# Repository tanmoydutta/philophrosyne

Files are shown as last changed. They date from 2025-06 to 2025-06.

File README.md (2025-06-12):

# Philophrosyne
A general purpose Bluetooth and WiFi enabled sensor board that has flexible interfaces for I2C, SPI Display and a SEN-54 seneor module.
The unit can be powered by USB-C connector or a LiPo battery. This module has built in battery charging circuit.
The model board - 
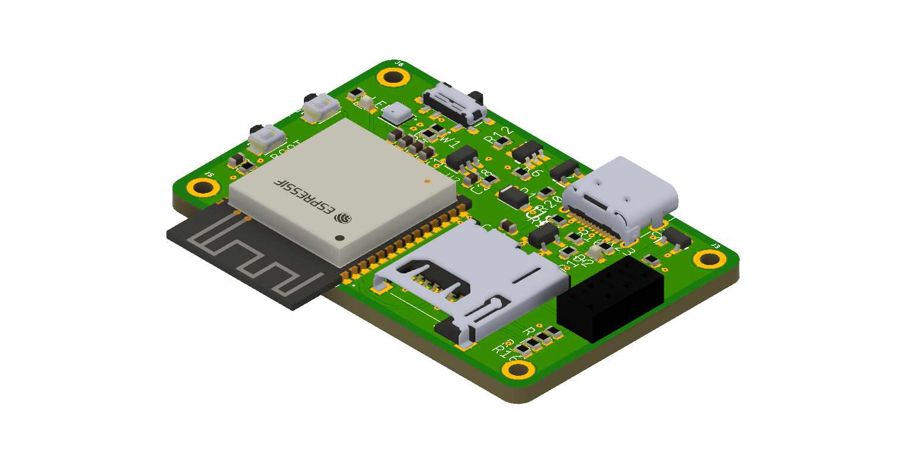
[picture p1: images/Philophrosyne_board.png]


Primary purpose of this board is to interface with SEN-54 sensors. A housing compatible with containing the sensor unit as well as the board is designed.

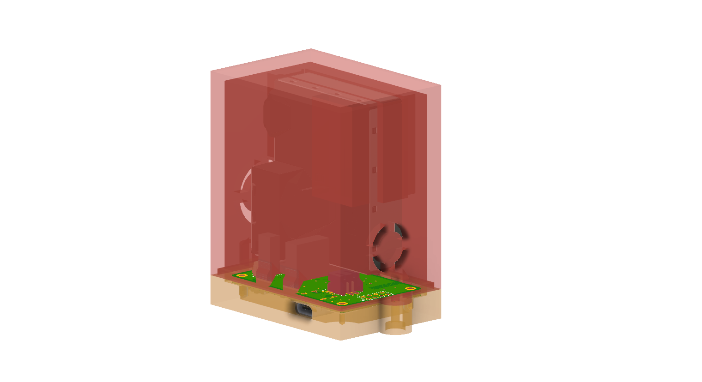
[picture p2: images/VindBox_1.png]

The concept module with coer removed-
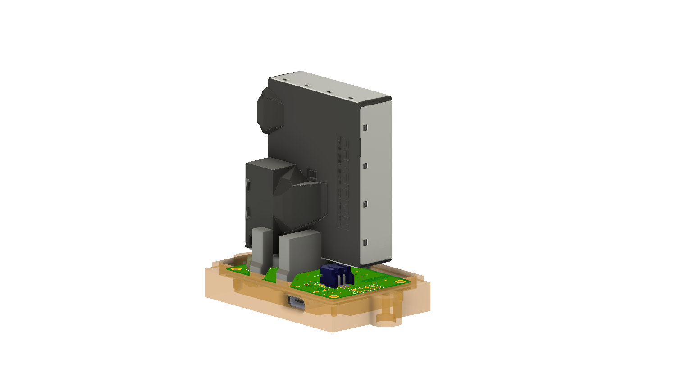
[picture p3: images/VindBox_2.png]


Below is the built module with the sensor and housing -


This is an OSHWA certified hardware - 
<p align="center">
  <a href="https://certification.oshwa.org/nl000030.html">
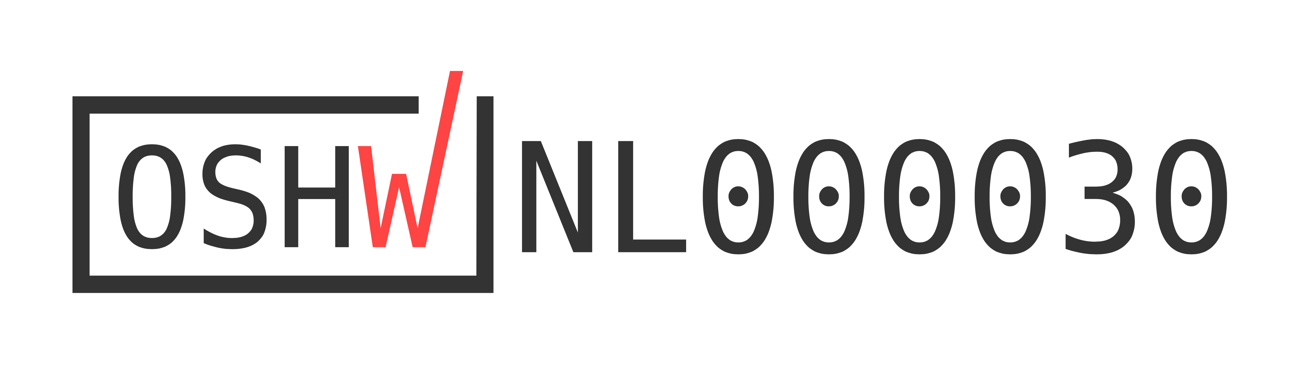
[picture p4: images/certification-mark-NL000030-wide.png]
OSHWA OSHWA Certification
    
  </a>
</p>



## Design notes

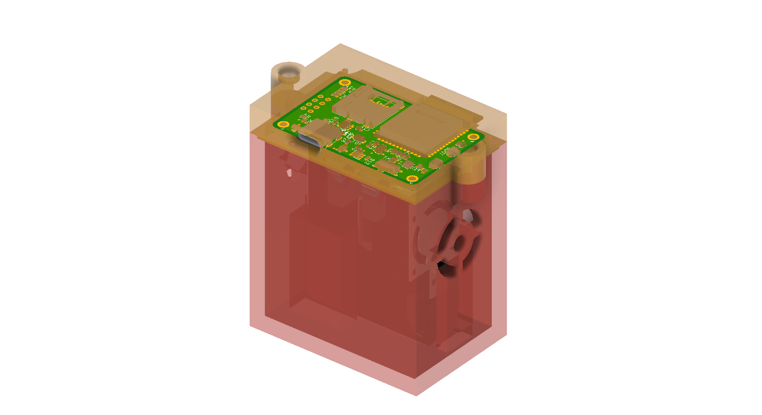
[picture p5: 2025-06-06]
images/VindBox_3.png

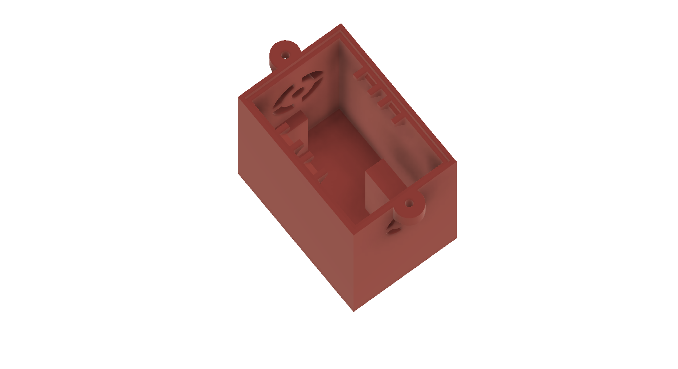
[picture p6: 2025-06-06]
images/VindBox_5.png

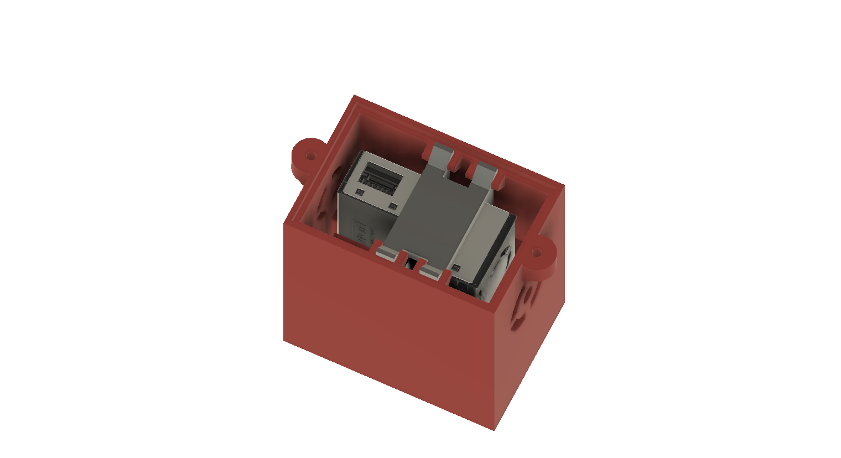
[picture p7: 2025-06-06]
images/VindBox_4.png

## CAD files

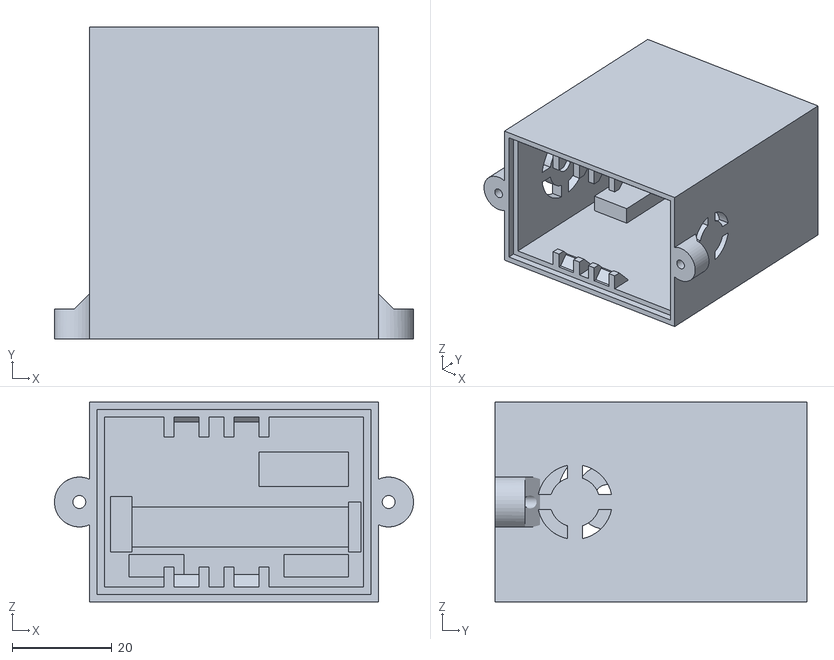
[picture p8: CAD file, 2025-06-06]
3D-files/VindBox_Bottom_v2.stl
72.0 x 62.5 x 40.0

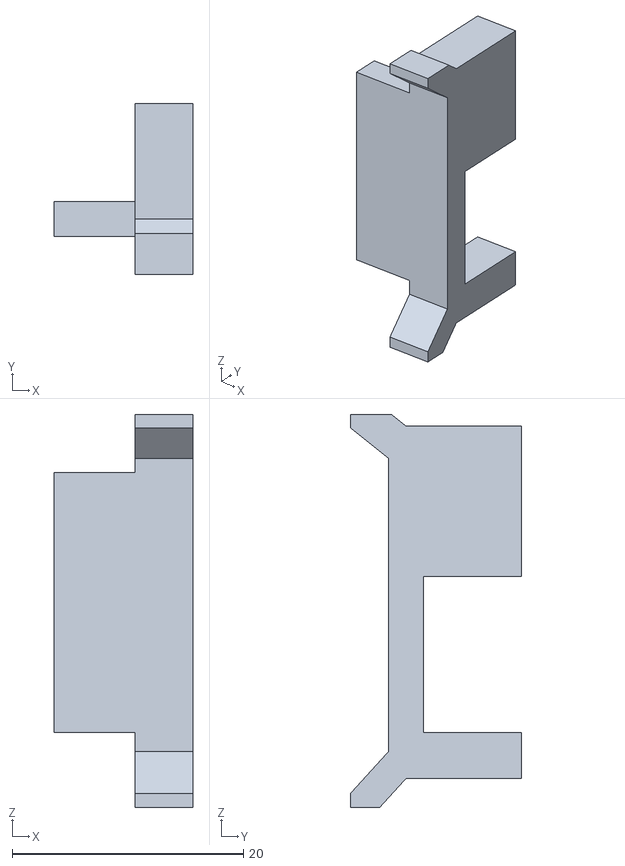
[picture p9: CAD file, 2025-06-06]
3D-files/VindBox_WideFoot.stl
12.0 x 14.8 x 34.0

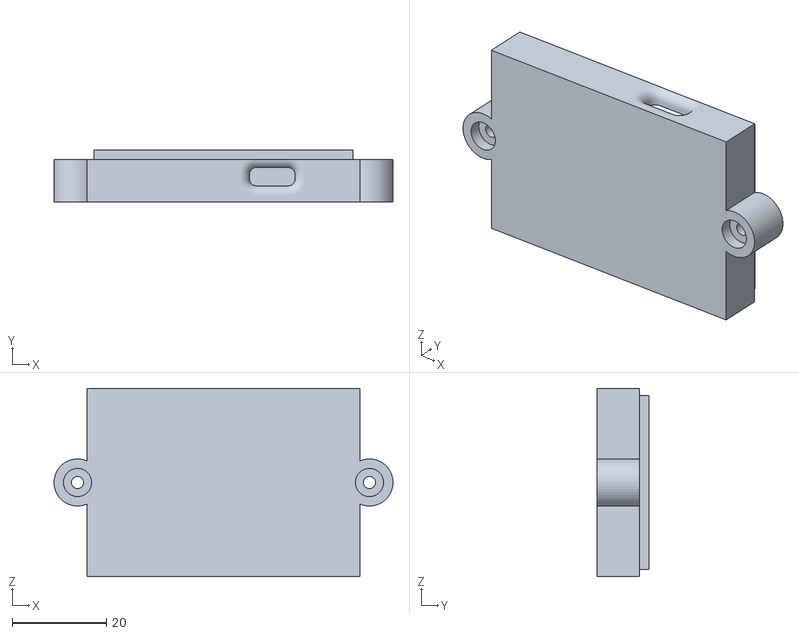
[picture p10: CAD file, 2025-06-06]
3D-files/VindBox_Top2.stl
72.0 x 11.0 x 40.0

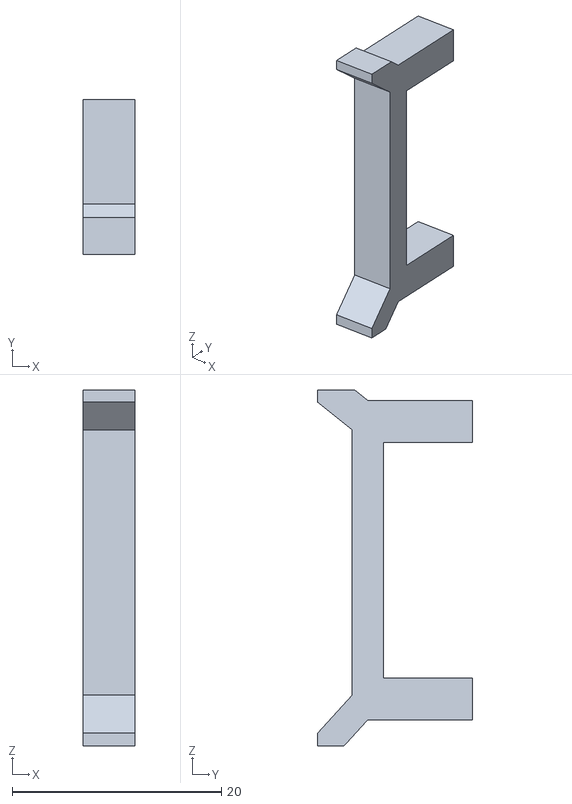
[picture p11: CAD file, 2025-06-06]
3D-files/VindBox_Foot.stl
5.00 x 14.8 x 34.0

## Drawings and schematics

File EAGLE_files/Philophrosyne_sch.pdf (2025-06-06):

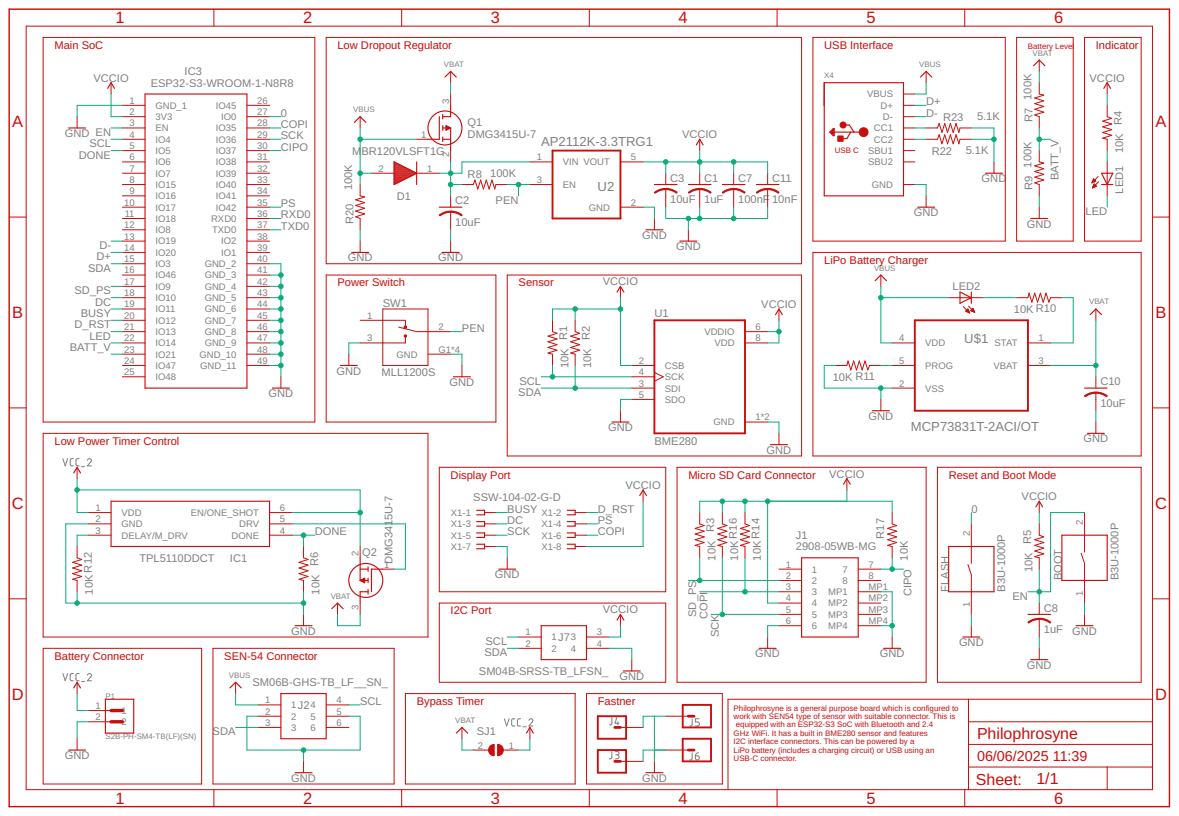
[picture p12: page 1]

Low Power Timer Control

Micro SD Card Connector

Reset and Boot Mode

Philophrosyne is a general purpose board which is configured to work with SEN54 type of sensor with suitable connector. This is equipped with an ESP32-S3 SoC with Bluetooth and 2.4 GHz WiFi. It has a built in BME280 sensor and features

I2C interface connectors. This can be powered by a
LiPo battery (includes a charging circuit) or USB using an USB-C connector.

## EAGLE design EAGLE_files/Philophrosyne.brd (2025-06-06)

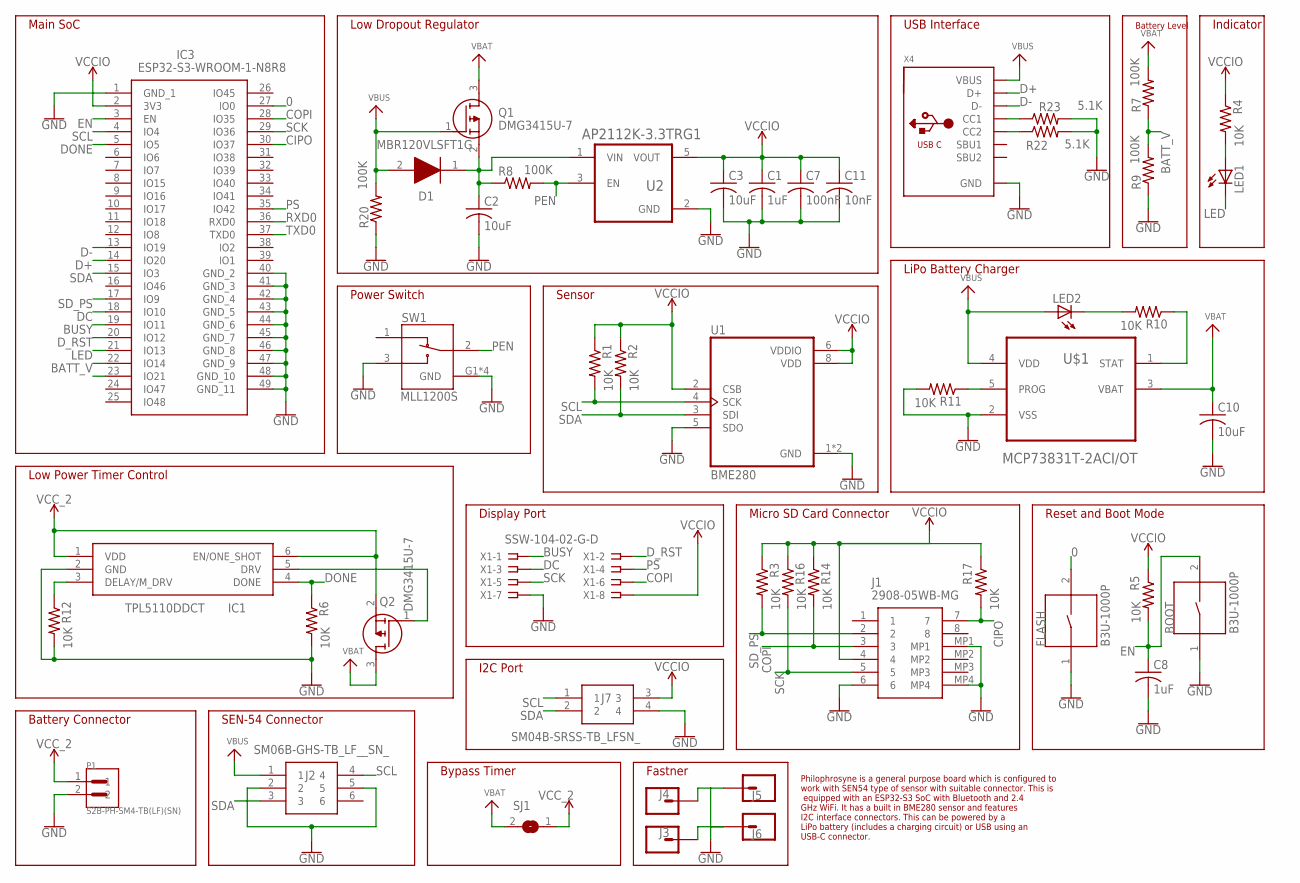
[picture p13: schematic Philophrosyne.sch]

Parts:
BOOT: B3U-1000P; SW_B3U-1000P
C1, C8: 1uF; C0402
C2, C3, C10: 10uF; C0402
C7: 100nF; C0402
C11: 10nF; C0402
D1: MBR120VLSFT1G; SODFL3616X98N
FLASH: B3U-1000P; SW_B3U-1000P
IC1: TPL5110DDCT; SOT95P280X110-6N
IC3: ESP32-S3-WROOM-1-N8R8; ESP32S3WROOM1N8R8
J1: 2908-05WB-MG; 290805WBMG
J2: SM06B-GHS-TB_LF__SN_; SM06B-GHS-TB
J3, J4, J5, J6: CONN_01PTH_2MM; 1X01_2MM
J7: SM04B-SRSS-TB_LFSN_; SM04B-SRSS-TB(LFSN)
LED1, LED2: LEDCHIP-LED0603; CHIP-LED0603
P1: S2B-PH-SM4-TB(LF)(SN); JST_S2B-PH-SM4-TB(LF)(SN)
Q1, Q2: DMG3415U-7; SOT96P240X100-3N
R1, R2, R3, R4, R5, R6, R10, R11, R12, R14, R16, R17: 10K; R0402
R7, R8, R9, R20: 100K; R0402
R22, R23: 5.1K; R0402
SJ1: SJ
SW1: MLL1200S; SW_MLL1200S
U1: BME280; PSON65P250X250X100-8N
U2: AP2112K-3.3TRG1; SOT95P285X140-5N
U$1: MCP73831T-2ACI/OT; SOT95P280X145-5N
X1: SSW-104-02-G-D
X4: MICROBUILDER_USB_C; MICROBUILDER_USB_C_CUSB31-CFM2AX-01-X

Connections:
0: FLASH.2, IC3.27 (IO0)
BATT_V: IC3.22 (IO14), R7.1, R9.2
BUSY: IC3.19 (IO11), X1.1
CIPO: IC3.30 (IO37), J1.7, R17.2
COPI: IC3.28 (IO35), J1.3, R14.2, X1.6
D+: IC3.14 (IO20), X4.A6 (D+), X4.B6 (D+)
D-: IC3.13 (IO19), X4.A7 (D-), X4.B7 (D-)
DC: IC3.18 (IO10), X1.3
DONE: IC1.4 (DONE), IC3.5 (IO5), R6.1
D_RST: IC3.20 (IO12), X1.2
EN: BOOT.2, C8.1, IC3.3 (EN), R5.2
GND: BOOT.1, C1.2, C2.2, C3.2, C7.2, C8.2, C10.2, C11.2, FLASH.1, IC1.2 (GND), IC3.1 (GND_1), IC3.40 (GND_2), IC3.41 (GND_3), IC3.42 (GND_4), IC3.43 (GND_5), IC3.44 (GND_6), IC3.45 (GND_7), IC3.46 (GND_8), IC3.47 (GND_9), IC3.48 (GND_10), IC3.49 (GND_11), J1.6, J1.MP1, J1.MP4, J2.2, J2.5, J3.1, J4.1, J5.1, J6.1, J7.4, P1.2, R6.2, R9.1, R11.2, R12.2, R20.1, R22.2, R23.2, SW1.3, SW1.G1 (GND), SW1.G2 (GND), SW1.G3 (GND), SW1.G4 (GND), U1.1 (GND), U1.5 (SDO), U1.7 (GND), U2.2 (GND), U$1.2 (VSS), X1.7, X4.A1B12 (GND), X4.B1A12 (GND)
LED: IC3.21 (IO13), LED1.C
unnamed: C2.1, D1.1 (K), Q1.2 (S), R8.1, U2.1 (VIN)
unnamed: R22.1, X4.B5 (CC2)
unnamed: R11.1, U$1.5 (PROG)
unnamed: R23.1, X4.A5 (CC1)
unnamed: LED1.A, R4.2
unnamed: IC1.5 (DRV), Q2.1 (G)
unnamed: R10.1, U$1.1 (STAT)
unnamed: LED2.C, R10.2
unnamed: IC1.3 (DELAY/M_DRV), R12.1
PEN: R8.2, SW1.2, U2.3 (EN)
PS: IC3.35 (IO42), X1.4
RXD0: IC3.36 (RXD0)
SCK: IC3.29 (IO36), J1.5, R16.2, X1.5
SCL: IC3.4 (IO4), J2.4, J7.1, R1.2, U1.4 (SCK)
SDA: IC3.15 (IO3), J2.3, J7.2, R2.2, U1.3 (SDI)
SD_PS: IC3.17 (IO9), J1.2, R3.2
TXD0: IC3.37 (TXD0)
VBAT: C10.1, Q1.3 (D), Q2.3 (D), R7.2, SJ1.2, U$1.3 (VBAT)
VBUS: D1.2 (A), J2.1, LED2.A, Q1.1 (G), R20.2, U$1.4 (VDD), X4.A4B9 (VBUS), X4.B4A9 (VBUS)
VCCIO: C1.1, C3.1, C7.1, C11.1, IC3.2 (3V3), J1.4, J7.3, R1.1, R2.1, R3.1, R4.1, R5.1, R14.1, R16.1, R17.1, U1.2 (CSB), U1.6 (VDDIO), U1.8 (VDD), U2.5 (VOUT), X1.8
VCC_2: IC1.1 (VDD), IC1.6 (EN/ONE_SHOT), P1.1, Q2.2 (S), SJ1.1

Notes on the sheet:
Main SoC
Low Dropout Regulator
Low Power Timer Control
Power Switch
Sensor
Display Port
Battery Connector
SEN-54 Connector
I2C Port
Bypass Timer
Fastner
Micro SD Card Connector
USB Interface
Battery Level
Indicator
LiPo Battery Charger
Reset and Boot Mode
Philophrosyne is a general purpose board which is configured to work with SEN54 type of sensor with suitable connector. This is equipped with an ESP32-S3 SoC with Bluetooth and 2.4 GHz WiFi. It has a built in BME280 sensor and features I2C interface connectors. This can be powered by a LiPo battery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

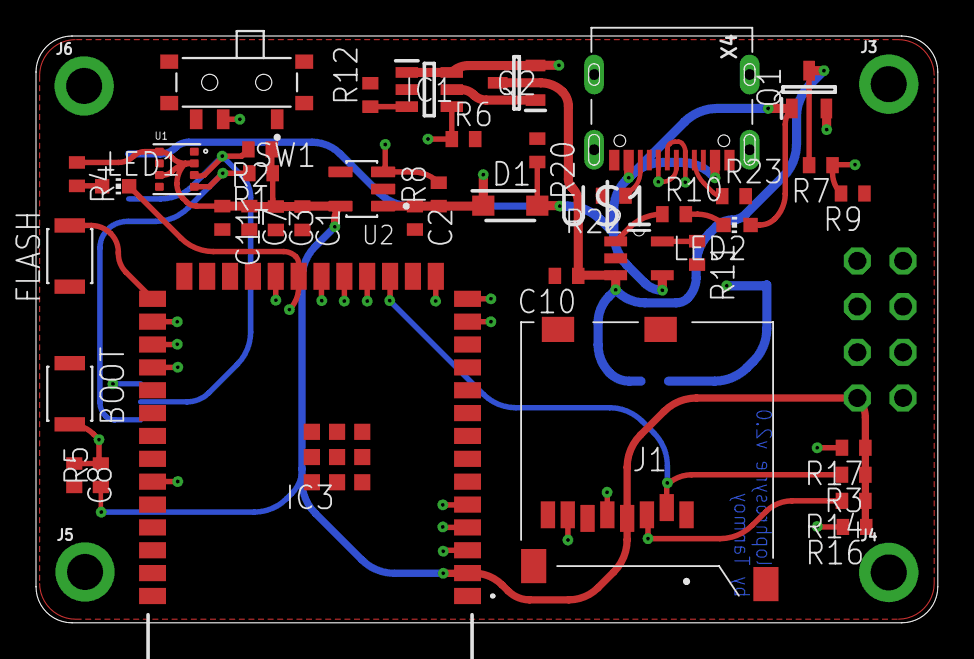
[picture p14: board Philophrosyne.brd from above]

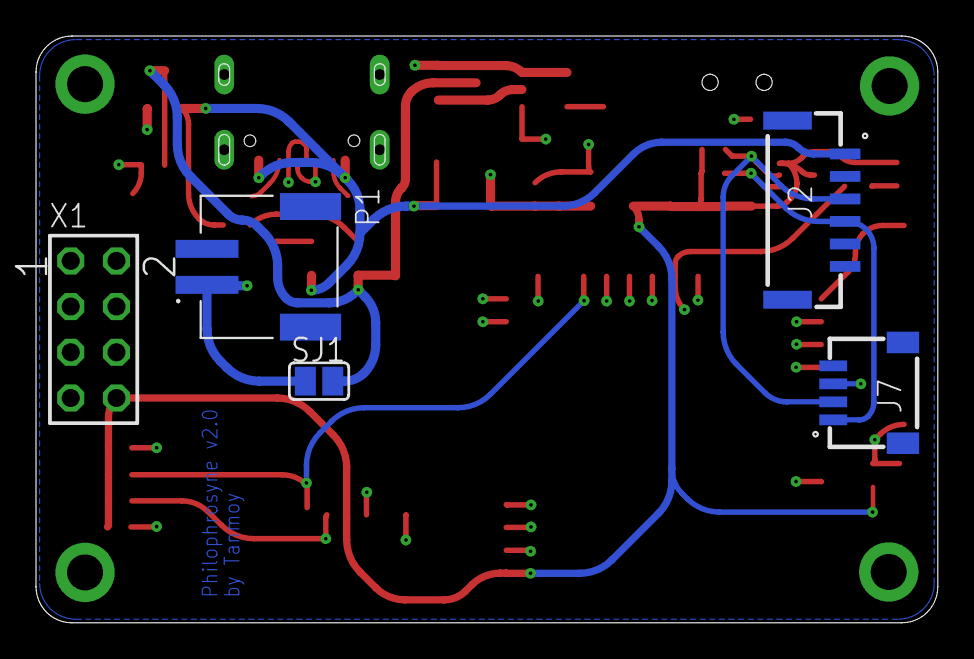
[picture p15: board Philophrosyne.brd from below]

Board: 4 copper layers, 50.1 x 32.6 mm, 49 parts (5 on the bottom side), 32 nets.

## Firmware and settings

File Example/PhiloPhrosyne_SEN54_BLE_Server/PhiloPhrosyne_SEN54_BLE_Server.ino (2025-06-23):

#include <Arduino.h>
#include <Wire.h>
#include <SensirionI2CSen5x.h>
#include <BLEDevice.h>
#include <BLEServer.h>
#include <BLEUtils.h>
#include <BLE2902.h>

#define INDICATOR_LED 13
// UUIDs
#define ENV_SERVICE_UUID "d0000000-0000-1000-8000-00805f9b34fb"
#define TEMP_UUID        "2A6E"
#define HUM_UUID         "2A6F"
#define VOC_UUID         "d0000004-0000-1000-8000-00805f9b34fb"
#define NOX_UUID         "d0000005-0000-1000-8000-00805f9b34fb"
#define PM25_UUID        "2BD3"

// The used commands use up to 48 bytes. On some Arduino's the default buffer
// space is not large enough
#define MAXBUF_REQUIREMENT 48

#if (defined(I2C_BUFFER_LENGTH) &&                 \
     (I2C_BUFFER_LENGTH >= MAXBUF_REQUIREMENT)) || \
    (defined(BUFFER_LENGTH) && BUFFER_LENGTH >= MAXBUF_REQUIREMENT)
#define USE_PRODUCT_INFO
#endif
// 
SensirionI2CSen5x sen5x;

unsigned long previousMillis = 0;  // will store last time LED was updated

// constants won't change:
const long interval = 30000;  // interval at which to blink (milliseconds)

// Helper: encode float to IEEE-11073 SFLOAT (2 bytes)
uint16_t encodeSFloat(float value) {
  if (isnan(value)) return 0x07FF;
  int8_t exponent = 0;
  int16_t mantissa = (int16_t)value;
  while ((mantissa < -2048 || mantissa > 2047) && exponent < 7) {
    exponent++;
    mantissa /= 10;
  }
  if (mantissa < -2048 || mantissa > 2047) return 0x07FF;
  return ((exponent & 0x0F) << 12) | (mantissa & 0x0FFF);
}

// Characteristic callback class for pull reads
class SensorCallback : public BLECharacteristicCallbacks {
  int sensorType;
public:
  SensorCallback(int type) : sensorType(type) {}

  void onRead(BLECharacteristic* pCharacteristic) override {
    float temp, hum, voc, nox, pm1p0, pm2p5, pm4p0, pm10p0;

    int16_t err = sen5x.readMeasuredValues(pm1p0, pm2p5, pm4p0, pm10p0, hum, temp, voc, nox);
    if (err != 0) {
      Serial.print("Sensor read error: ");
      Serial.println(err);
      return;
    }

    float val = 0.0;
    switch(sensorType) {
      case 0: val = temp; break;
      case 1: val = hum; break;
      case 2: val = voc; break;
      case 3: val = nox; break;
      case 4: val = pm2p5; break;
      default: val = 0; break;
    }

    uint16_t encoded = encodeSFloat(val);
    uint8_t buf[2] = { (uint8_t)(encoded & 0xFF), (uint8_t)(encoded >> 8) };
    pCharacteristic->setValue(buf, 2);

    Serial.print("Sent value type ");
    Serial.print(sensorType);
    Serial.print(": ");
    Serial.println(val);
  }
};

// Helper to create characteristic with callback
BLECharacteristic* createChar(BLEService* service, const char* uuid, const char* description, int type) {
  BLECharacteristic* ch = service->createCharacteristic(uuid, BLECharacteristic::PROPERTY_READ);
  ch->setCallbacks(new SensorCallback(type));

  BLEDescriptor* desc = new BLEDescriptor(BLEUUID((uint16_t)0x2901));
  desc->setValue(description);
  ch->addDescriptor(desc);

  return ch;
}

class ServerCallbacks : public BLEServerCallbacks {
  void onConnect(BLEServer* pServer) {
    Serial.println("Client connected.");
  }

  void onDisconnect(BLEServer* pServer) {
    Serial.println("Client disconnected. Restarting advertising...");
    delay(100);
    pServer->startAdvertising();
  }
};

void setup() {
  Serial.begin(115200);
  //while (!Serial){}
  pinMode(INDICATOR_LED, OUTPUT);
  Wire.begin();

  sen5x.begin(Wire);
//////
    uint16_t error;
    char errorMessage[256];
    error = sen5x.deviceReset();
    if (error) {
        Serial.print("Error trying to execute deviceReset(): ");
        errorToString(error, errorMessage, 256);
        Serial.println(errorMessage);
    }
    //delay(2000);


    float tempOffset = 0.0;
    error = sen5x.setTemperatureOffsetSimple(tempOffset);
    if (error) {
        Serial.print("Error trying to execute setTemperatureOffsetSimple(): ");
        errorToString(error, errorMessage, 256);
        Serial.println(errorMessage);
    } else {
        Serial.print("Temperature Offset set to ");
        Serial.print(tempOffset);
        Serial.println(" deg. Celsius (SEN54/SEN55 only");
    }
    delay(2000);
    // Start Measurement
    error = sen5x.startMeasurement();
    if (error) {
        Serial.print("Error trying to execute startMeasurement(): ");
        errorToString(error, errorMessage, 256);
        Serial.println(errorMessage);
    }
//////



  BLEDevice::init("ESP32-SEN54");
  BLEServer* server = BLEDevice::createServer();
  server->setCallbacks(new ServerCallbacks());
  BLEService* service = server->createService(ENV_SERVICE_UUID);
/////

/////
  createChar(service, TEMP_UUID, "Temperature (°C)", 0);
  createChar(service, HUM_UUID, "Humidity (%)", 1);
  createChar(service, VOC_UUID, "VOC Index", 2);
  createChar(service, NOX_UUID, "NOx Index", 3);
  createChar(service, PM25_UUID, "PM2.5 (ug/m3)", 4);

  service->start();

  BLEAdvertising* advertising = BLEDevice::getAdvertising();
  advertising->addServiceUUID(ENV_SERVICE_UUID);
  advertising->start();

  Serial.println("BLE server started. Waiting for clients...");
}

void loop() {
  unsigned long currentMillis = millis();

  if (currentMillis - previousMillis >= interval) {
    // save the last time you blinked the LED
    previousMillis = currentMillis;
    digitalWrite(INDICATOR_LED, LOW);
    delay(25);
    digitalWrite(INDICATOR_LED, HIGH);
    delay(1000);
  } else {
    delay(1000);
  }
}

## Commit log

2025-06-06 Adding files
    [Philophrosyne.brd, Philophrosyne.sch, VindBox_Bottom_v2.stl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]
2025-06-23 Adding a sample sketch

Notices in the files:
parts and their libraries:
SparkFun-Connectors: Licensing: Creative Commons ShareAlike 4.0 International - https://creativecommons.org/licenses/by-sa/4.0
